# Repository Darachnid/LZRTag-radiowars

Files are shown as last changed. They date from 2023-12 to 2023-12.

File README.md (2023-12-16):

# [LZRTag](https://hackaday.io/project/160804-lzrtag-flexible-diy-lasertag)

### ESP32-Based Lasertag

Ever wanted to set up your own system of Lasertag?
Interested in having an easily modifiable system to create your own gamemodes and styles with?
Or just looking for a cool project to try out?
Well, why not take a spin at this!

*Note:* This project is not in serious development. I (Xasin) take no responsibility for what is done with this code, and I can't guarantee it'll do exactly what I tell it to (even if I try to give it treats >:c)
However, it is a fully functional system, if you know how to use it, and it has proven itself
to be pretty reliable and useful!

## The components
In order to have a functional game, you will need at least the following:
- Two or more soldered Lasertag Sets
- A WiFi access point or a newtwork of points throughout the arena.
- A MQTT Server, preferrably in the local network, to reduce ping.
- And a system running Ruby 2.4 or better, to run the Lasertag Backend and your gamemodes

## The Electronics
*Attention:* The electronics aren't necessarily beginner-friendly. I've designed them with components no smaller than a TSOP package or a 0805 resistor, but the newer versions of the hardware do include two QFN Packages - one for a optional IMU, so it can be left out, and one for a standard I2S audio chip, for which you can use any breakout board that supports 44100Hz, 16 bit playback. If you have a hot air gun,
definitely make use of it!

The electronics are based around the ESP32, a fairly cheap, powerful, WiFi and Bluetooth capable chip. The PCB includes all necessary support structures, including a battery charge circuit and a USB to UART converter to reprogram and debug the ESP.
It comes with the following hardware:
- The ESP32 plus beefy voltage regulation, ESD protection, etc. It ain't gonna break!
- A MAX I2S decoder + amplifier, for on-board, high quality audio.
- A LSM6D IMU, to detect movement, collisions, gestures, etc.
- Peripherals to receive and send IR Signals (documented here: TODO)
- Feedback in the shape of WS2812 LEDs and a vibration motor
- Trigger, Gun Select and Reload buttons.

The vest connection is exposed with a D-SUB connector, and I2C lines are available to make
more complex add-ons easier to achieve. There's also a I2C breakout connection on the PCB itself!

The Vest itself can be as simple as a couple of Vishay 40kHz IR receivers and WS2812 LEDs, but
there is a connection for vest-specific haptic feedback, and via the I2C connection it's easy to add
more complex features.

To solder one, check out the Aisler project here: https://aisler.net/p/QLILZEMV
Or head to the "Electronics" folder and generate your own Gerber files!

## The Casing
The 3D printed casing I designed is totally optional - the electronics can be easily fitted into any other casing, provided it has space for a switch, a speaker and a couple of LEDs!
However, if you do want to print it out, there's the Fusion360 page here: https://a360.co/2Lbm2zJ

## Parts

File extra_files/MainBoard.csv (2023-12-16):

Quantity | Digi-Key_PN
1 | 1904-1025-1-ND
1 | AE10921-ND
1 | 1830-1068-1-ND
1 | 160-1172-1-ND
1 | MAX98357AETE+TCT-ND
1 | 668-1517-ND
1 | 455-1749-1-ND
1 | IRLML6402PBFCT-ND
2 | CD0603-B0340RCT-ND
1 | CKN9565-ND
1 | AP2114H-3.3TRG1DICT-ND
1 | MAX1555EZK+TCT-ND
1 | F7701CT-ND
1 | 732-5960-1-ND
1 | 768-1129-1-ND
4 | 1727-2956-1-ND
1 | 1528-1104-ND
1 | EG1701-ND
1 | 1597-1244-ND
1 | 475-3581-ND
1 | 497-15383-1-ND
1 | 1568-1214-ND
1 | 1568-1827-ND

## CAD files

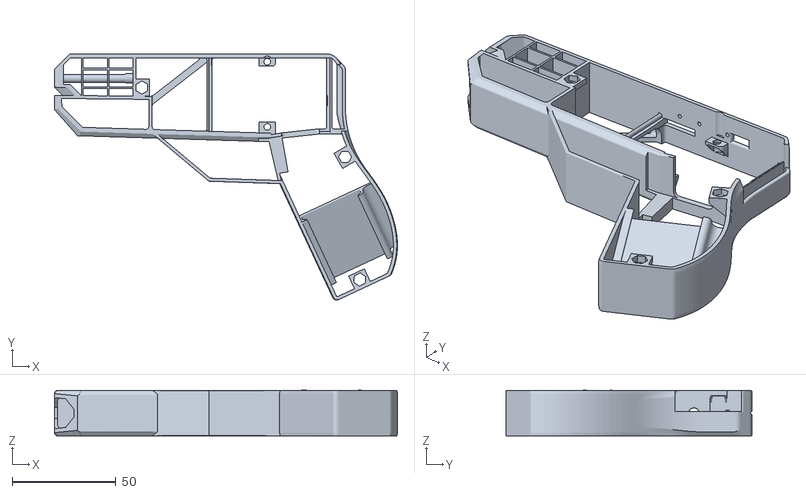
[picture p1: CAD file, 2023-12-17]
extra_files/Lasertag_Case/Lasertag_Case/Core_MAIN.stl
165.1 x 118.5 x 22.1

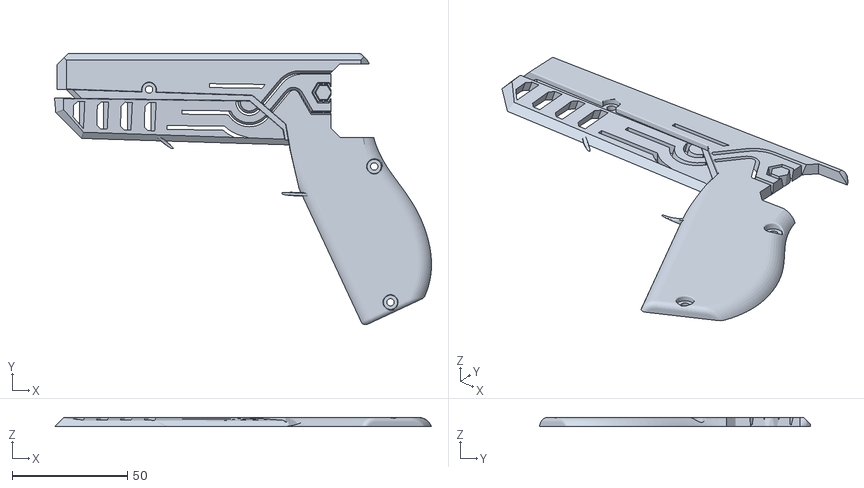
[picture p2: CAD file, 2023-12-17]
extra_files/Lasertag_Case/Lasertag_Case/Top/Top_MAIN.stl
163.7 x 117.8 x 4.00

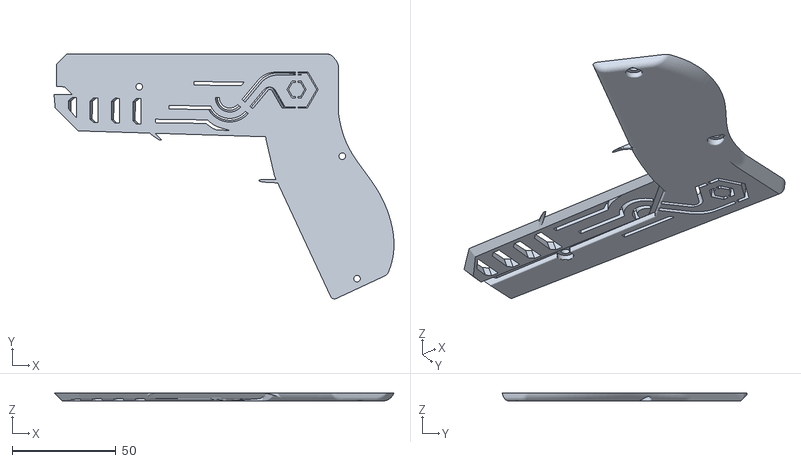
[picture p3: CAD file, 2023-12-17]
extra_files/Lasertag_Case/Lasertag_Case/Bottom/Bottom_MAIN.stl
163.7 x 117.8 x 4.00

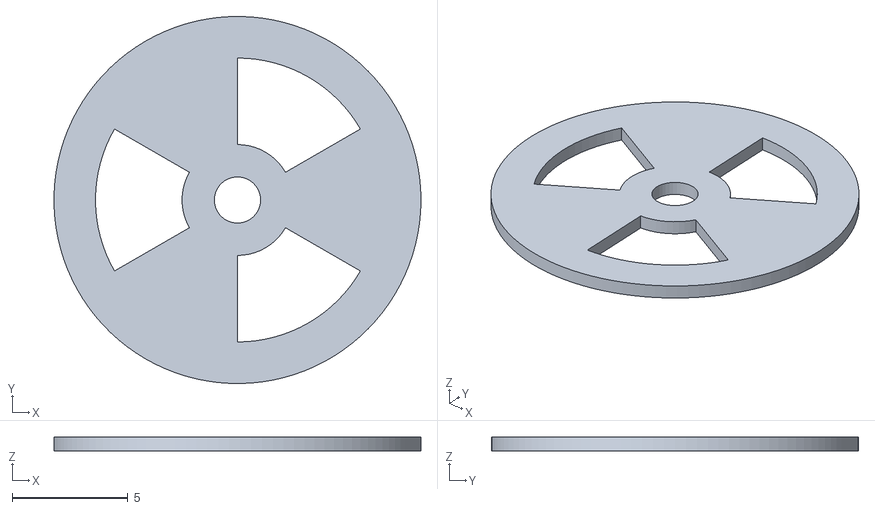
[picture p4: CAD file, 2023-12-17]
extra_files/Lasertag_Case/Lasertag_Case/Bottom/Bottom_MARKING2.stl
15.9 x 15.9 x 0.6

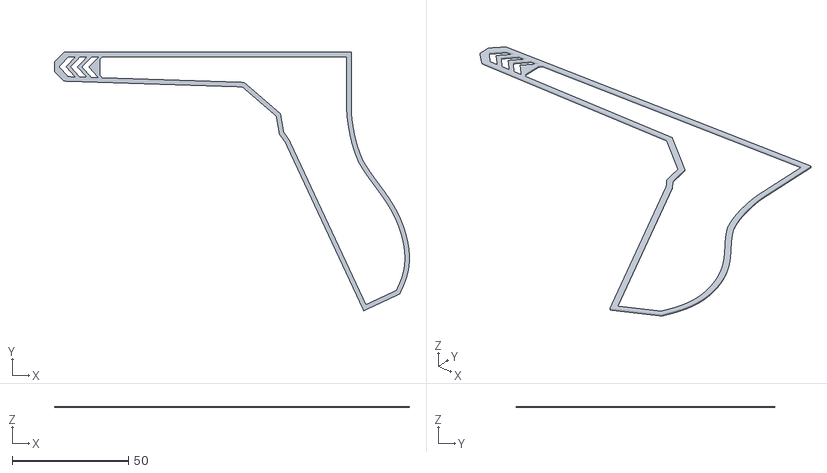
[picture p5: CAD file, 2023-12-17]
extra_files/Lasertag_Case/Lasertag_Case/Bottom/Bottom_MARKING1.stl
152.9 x 111.3 x 0.6

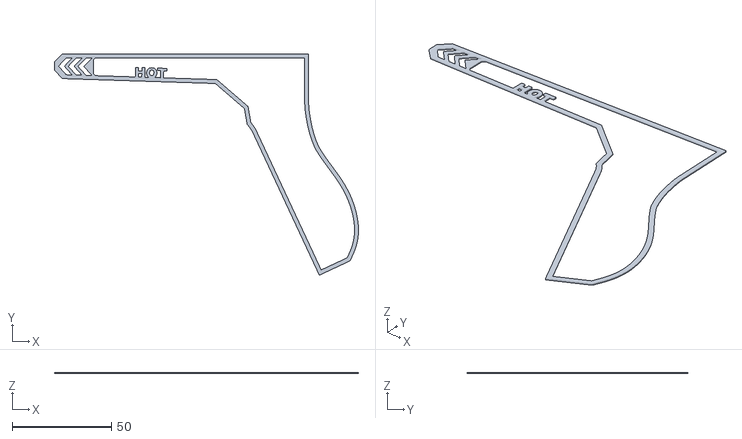
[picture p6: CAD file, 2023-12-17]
extra_files/Lasertag_Case/Lasertag_Case/Top/Top_MARKING1.stl
152.9 x 111.3 x 0.6

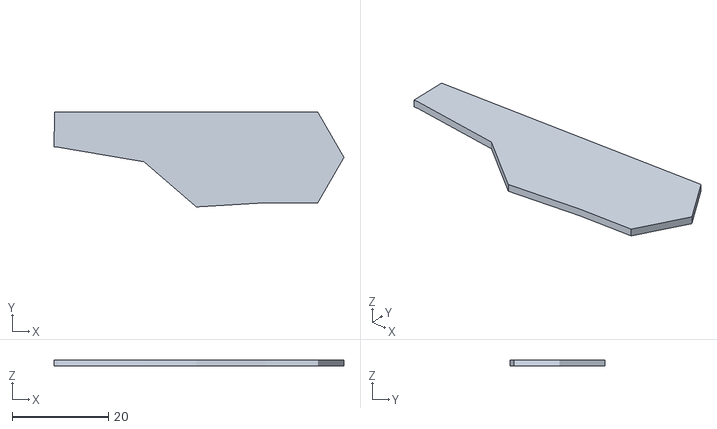
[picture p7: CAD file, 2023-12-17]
extra_files/Lasertag_Case/Lasertag_Case/Bottom/Bottom_TRANSPARENT3.stl
60.4 x 19.8 x 1.30

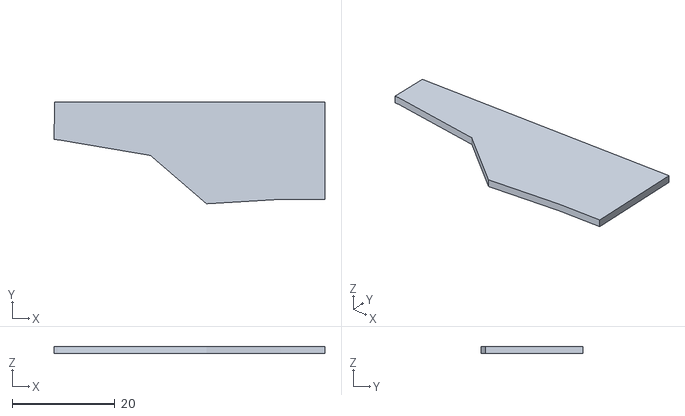
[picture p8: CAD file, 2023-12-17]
extra_files/Lasertag_Case/Lasertag_Case/Top/Top_TRANSPARENT3.stl
52.7 x 19.8 x 1.30

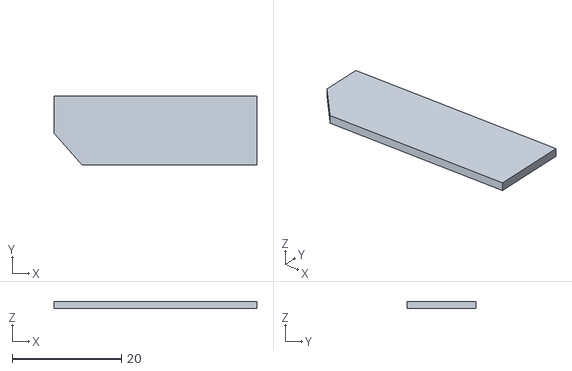
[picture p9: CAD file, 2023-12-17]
extra_files/Lasertag_Case/Lasertag_Case/Bottom/Bottom_TRANSPARENT1.stl
37.2 x 12.7 x 1.30

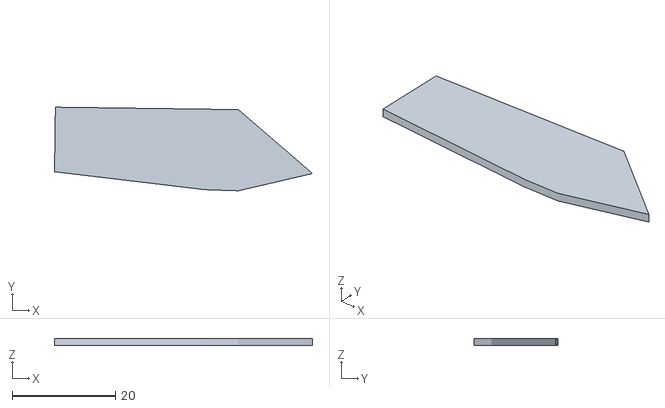
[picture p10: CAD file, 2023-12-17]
extra_files/Lasertag_Case/Lasertag_Case/Top/Top_TRANSPARENT2.stl
50.1 x 16.2 x 1.30

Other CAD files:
extra_files/Lasertag_Case/Lasertag_Case/Top/Top_TRANSPARENT1.stl
extra_files/Lasertag_Case/Lasertag_Case/Bottom/Bottom_TRANSPARENT2.stl
extra_files/Lasertag_Case/Lasertag_Case/Top/Top_MARKING2.stl

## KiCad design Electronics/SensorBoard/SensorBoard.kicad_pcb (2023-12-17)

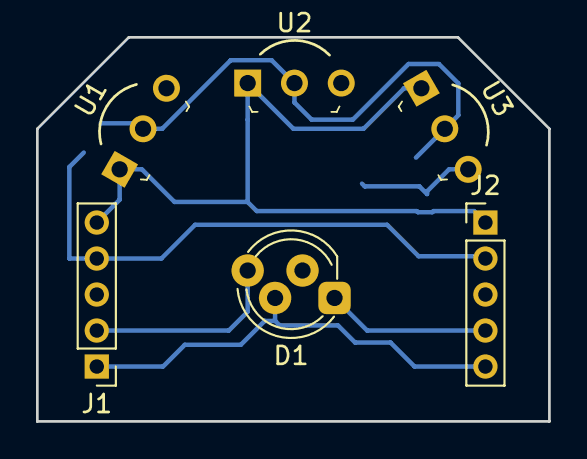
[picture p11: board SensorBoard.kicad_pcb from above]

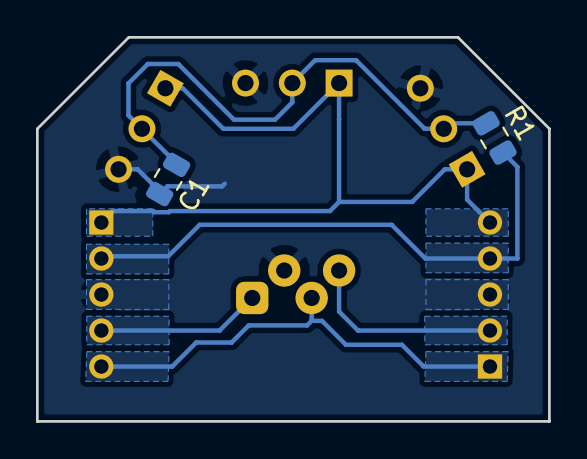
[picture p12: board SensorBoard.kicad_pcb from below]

Board: 2 copper layers, 28.4 x 21.3 mm, 8 parts (2 on the bottom side), 7 nets.

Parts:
C1: C_Small; C_0805_2012Metric
D1: NeoPixel_THT; LED_D5.0mm-4_RGB_Staggered_Pins
J1, J2: Conn_01x05_Male; PinHeader_1x05_P2.00mm_Vertical
R1: R_Small; R_0805_2012Metric
U1, U2, U3: TSSP58038; TO-92-3_Formed_Leads

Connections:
+3V3: J1.4, J2.2, R1.2
+BATT: D1.3, J1.1, J2.5
GND: C1.2, D1.2, J1.3, J2.3, U1.3, U2.3, U3.3
unnamed: C1.1, R1.1, U1.2, U2.2, U3.2
unnamed: D1.1, J2.4
unnamed: D1.4, J1.2
unnamed: J1.5, J2.1, U1.1, U2.1, U3.1

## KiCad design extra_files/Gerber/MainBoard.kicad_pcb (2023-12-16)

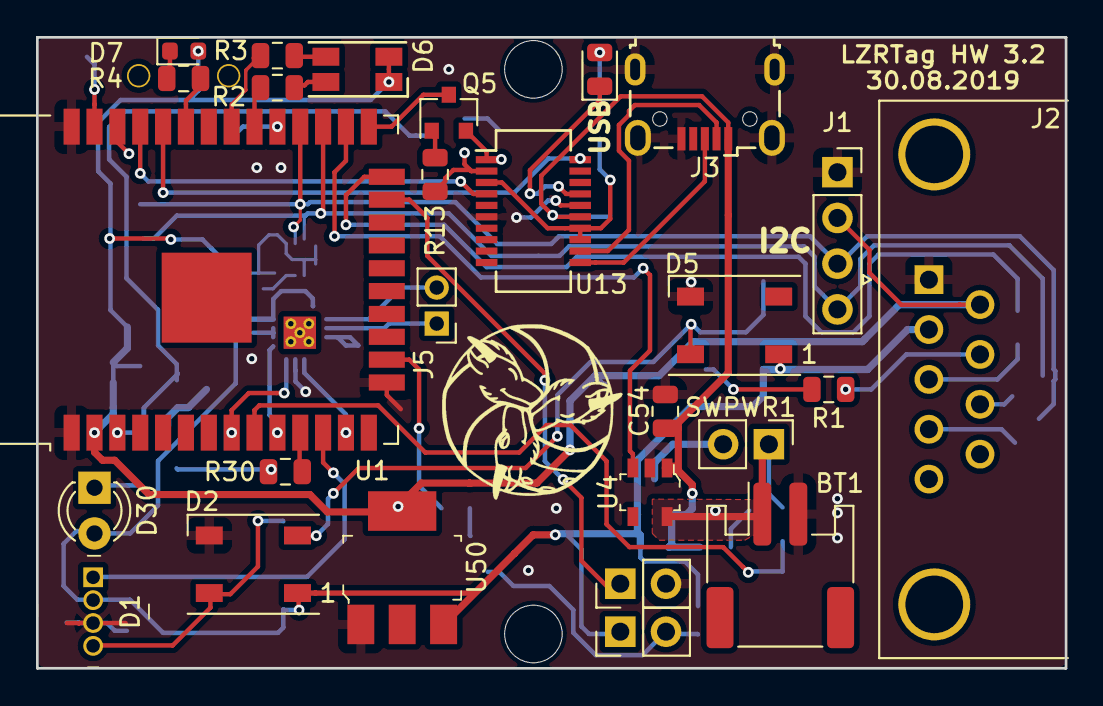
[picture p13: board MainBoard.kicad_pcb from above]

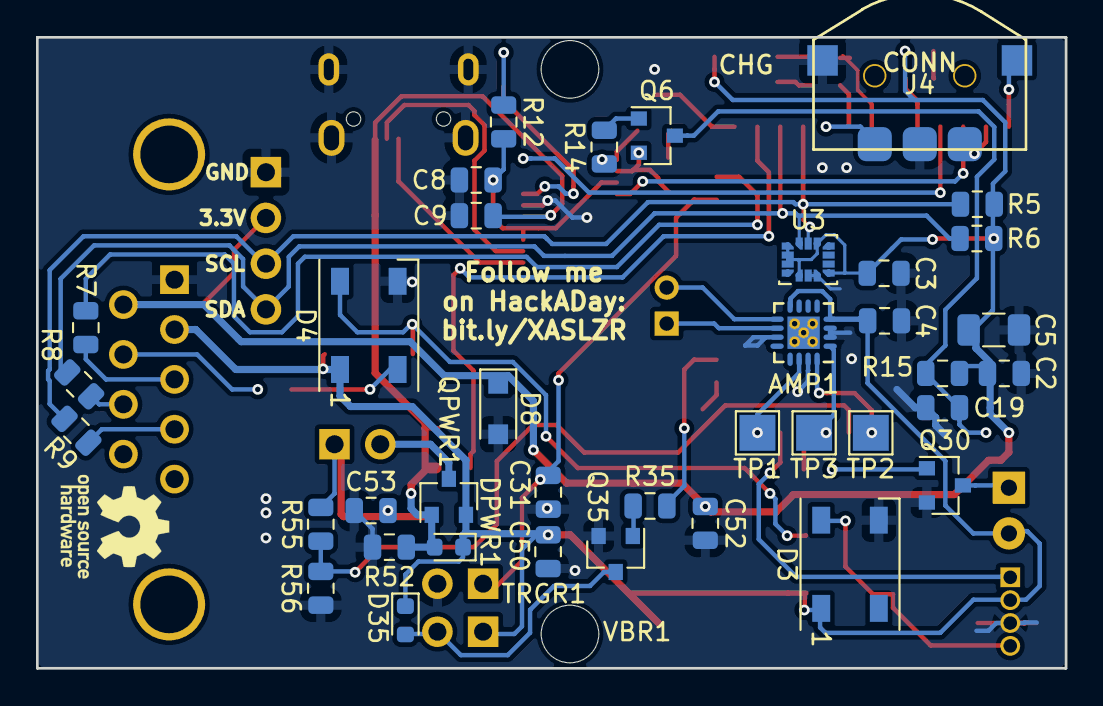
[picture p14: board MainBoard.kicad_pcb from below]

Board: 2 copper layers, 57.2 x 35.1 mm, 70 parts (40 on the bottom side), 53 nets.

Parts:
AMP1: MAX98357A; QFN-16-1EP_3x3mm_P0.5mm_EP2.7x2.7mm_ThermalVias
BT1: Battery_Cell; JST_PH_S2B-PH-SM4-TB_1x02-1MP_P2.00mm_Horizontal
C2, C8, C31: 150nF; C_0805_2012Metric
C3: 0.1uF; C_0805_2012Metric
C4, C9, C52, C53: 10uF; C_0805_2012Metric
C5: 47uF; C_1206_3216Metric
C19: 100nF; C_0805_2012Metric
C50, C54: 1uF; C_0805_2012Metric
D1: COM-12999; LED_RGB_WP154A4SUREQBFZGC
D2, D3, D4, D5: WS2812B; LED_WS2812B_PLCC4_5.0x5.0mm_P3.2mm
D6: LED_Dual_AACC; LED_RGB_1210
D7: LED; LED_0603_1608Metric
D8: D_Zener_ALT; D_SOD-123F
D30: SFH4346; LED_D3.0mm_IRBlack
D35: D_Schottky; D_0603_1608Metric
DPWR1: D_Schottky; D_0603_1608Metric
DUSB1: LED; LED_0805_2012Metric
H1, H2: MountingHole; MountingHole_3.2mm_M3_DIN965
H3: MountingHole; KiCad-Logo_5mm_SolderMask
H4: MountingHole; OSHW-Logo_5.7x6mm_SilkScreen
H6: MountingHole; DragonIcon
J1: Conn_01x04_Female; PinSocket_1x04_P2.54mm_Vertical
J2: DB9_Female; DSUB-9_Female_Horizontal_P2.77x2.84mm_EdgePinOffset4.94mm_H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
J3: USB_B_Micro; USB_Micro-B_Wuerth_629105150521
J4: Conn_01x04_Male; nav_switch_COM_08184
J5: Conn_01x02_Male; PinHeader_1x02_P2.00mm_Vertical
Q5, Q6: Q_NPN_BEC; SOT-23
Q30, Q35: PMBT2222A; SOT-23
QPWR1: IRLML6402; SOT-23
R1, R4, R7, R8, R9, R12, R30: 220; R_0805_2012Metric
R2, R3: 220R; R_0805_2012Metric
R5, R6, R35: 2.2k; R_0805_2012Metric
R13, R14, R15: R_Small; R_0805_2012Metric
R52: 10k; R_0805_2012Metric
R55: 100k; R_0805_2012Metric
R56: 200k; R_0805_2012Metric
SWPWR1: SW_SPST; PinHeader_1x02_P2.54mm_Vertical
TP1, TP2, TP3: TestPoint; TestPoint_Pad_2.0x2.0mm
TRGR1: SW_Push; PinHeader_1x02_P2.54mm_Vertical
U1: ESP32-WROOM-32
U3: LSM6DS3; LGA-14_3x2.5mm_P0.5mm_LayoutBorder3x4y
U4: MAX1555EZK_T; SOT-753
U13: FT231XS; SSOP-20_3.9x8.7mm_P0.635mm
U50: AP2114H-3_3TRG1; SOT-223
VBR1: Motor_DC_ALT; PinHeader_1x02_P2.54mm_Vertical

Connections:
+3V3: C2.1, C3.2, C5.2, C52.1, D6.1, D6.2, D7.2, D8.1, J1.2, J2.6, R5.1, R6.1, R15.1, U1.2, U3.1, U3.2, U3.3, U3.5, U3.8, U3.12, U50.4
+BATT: AMP1.4, AMP1.8, C4.1, C50.1, D1.2, D2.1, D3.1, D4.1, D5.1, D30.2, D35.1, DPWR1.1, J2.2, QPWR1.2, U50.3, VBR1.1
/AUDIO: AMP1.1, TP3.1, U1.10
/BCLK: AMP1.16, TP2.1, U1.8
/CHG_G: R3.2, U1.31
/CHG_R: R2.2, U1.30
/CHG_STAT: U1.26, U4.3
/CONN_IND: R4.2, U1.33
/CTRL_BACK: J4.1, U1.29
/CTRL_DOWN: J4.4, U1.37
/CTRL_FWD: J4.3, U1.36
/E>U: U1.35, U13.4
/GPIO0: Q5.3, U1.25
/IR_IN: R7.2, U1.24
/IR_OUT: R30.2, U1.11
/LED_1: D1.1, U1.12
/LED_2: D4.2, R1.2
/LRCLK: AMP1.14, TP1.1, U1.13
/PowerHandling/B_Raw+: BT1.1, C53.1, R55.1, SWPWR1.1, U4.5
/RESET: C19.1, Q6.3, R15.2, U1.3
/TRIGGER: C31.1, TRGR1.1, U1.23
/U>E: U1.34, U13.20
/USB Connection/+5V_USB: C9.2, C54.1, DPWR1.2, J3.1, QPWR1.1, R52.1, U4.1, U13.15
/USB Connection/USB3.3: C8.2, R12.1, U13.3, U13.13, U13.14
/VBRT: R35.2, U1.16
/V_SENSE: R55.2, R56.1, U1.9
GND: AMP1.2, AMP1.3, AMP1.11, AMP1.15, BT1.2, C2.2, C3.1, C4.2, C5.1, C8.1, C9.1, C19.2, C31.2, C50.2, C52.2, C53.2, C54.2, D1.3, D2.3, D3.3, D4.3, D5.3, D8.2, J1.1, J2.1, J3.5, J3.6, J4.2, Q30.2, Q35.2, R52.2, R56.2, TRGR1.2, U1.1, U1.15, U1.38, U3.6, U3.7, U4.2, U13.6, U13.16, U50.1
unnamed: AMP1.9, J5.2
unnamed: AMP1.10, J5.1
unnamed: D1.4, D2.4, D3.4
unnamed: D2.2, D4.4, D5.4
unnamed: D6.3, R3.1
unnamed: D6.4, R2.1
unnamed: D7.1, R4.1
unnamed: D30.1, Q30.3
unnamed: D35.2, Q35.3, VBR1.2
unnamed: DUSB1.1, U13.17
unnamed: DUSB1.2, R12.2
unnamed: J2.3, R7.1
unnamed: J2.4, R9.1
unnamed: J2.7, R1.1
unnamed: J2.8, R8.1
unnamed: J3.2, U13.12
unnamed: J3.3, U13.11
unnamed: Q5.1, R13.1
unnamed: Q5.2, R14.2, U13.1
unnamed: Q6.1, R14.1
unnamed: Q6.2, R13.2, U13.2
unnamed: Q30.1, R30.1
unnamed: Q35.1, R35.1
unnamed: QPWR1.3, SWPWR1.2
SCL: J1.3, R5.2, R9.2, U1.28, U3.13
SDA: J1.4, R6.2, R8.2, U1.27, U3.14

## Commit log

2023-12-16 add files via upload from hackaday, etc
    [MainBoard.csv, MainBoard.kicad_pcb]
2023-12-16 added gerber exports for pcb printing
    [MainBoard-B_Cu.gbr, MainBoard-B_Mask.gbr, MainBoard-B_Paste.gbr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]
